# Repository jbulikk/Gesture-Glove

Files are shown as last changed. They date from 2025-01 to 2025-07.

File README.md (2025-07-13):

# Gesture Glove
The purpose of this project is to design and implement a prototype glove for gesture-based computer control, equipped with a set of sensors and a microcontroller. 

The project integrates flex sensors that measure finger bending and an inertial module containing an accelerometer and gyroscope, enabling gesture recognition based on spatial orientation. A key system component is the decision unit, which analyses sensor data and compares it with predefined patterns. Recognized
gestures are then transmitted to the computer via a USB HID interface.

The designed PCB, measuring 47.5 mm by 54.5 mm, was created to optimize the system's dimensions and facilitate durable mounting on the glove.
The results include successful recognition gestures and seamless
integration with the computer via USB HID. 

Future development plans involve further PCB miniaturization using a dedicated integrated circuit, the introduction of a wireless communication interface, and the design of a battery-powered system. Additionally, optimization of the decision algorithm is planned to improve gesture recognition accuracy.

# Overview

🎥 [Demo 1](https://youtube.com/shorts/HhJ9UxrMhsA?si=5mQ5Ls-5uZ076j6t)
🎥 [Demo 2](https://youtube.com/shorts/HhJ9UxrMhsA?si=OoEMOWHLwrecI-b9)


rekawica

pajak

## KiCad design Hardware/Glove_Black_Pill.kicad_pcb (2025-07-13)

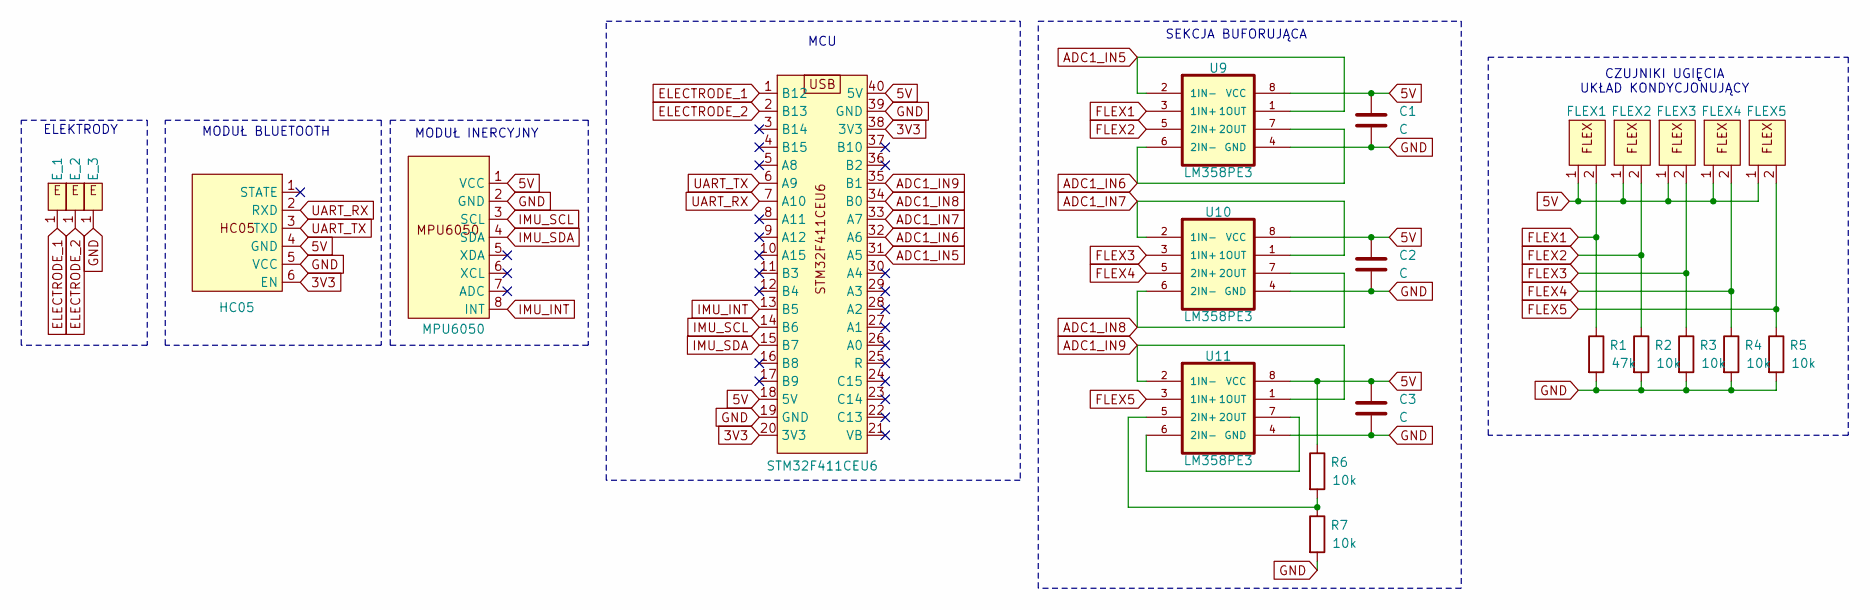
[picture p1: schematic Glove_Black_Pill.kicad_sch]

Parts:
C1, C2, C3: C; R_0805_2012Metric_Pad1.20x1.40mm_HandSolder
E_1, E_2, E_3: TestPoint_Loop_D2.50mm_Drill1.0mm
FLEX1, FLEX2, FLEX3, FLEX4, FLEX5: FLEX
HC05: HC-05
MPU6050: MPU6050
R1: 47k; R_0805_2012Metric_Pad1.20x1.40mm_HandSolder
R2, R3, R4, R5, R6, R7: 10k; R_0805_2012Metric_Pad1.20x1.40mm_HandSolder
STM32F411CEU6: STM32F411CEU6
U9, U10, U11: LM358PE3; DIP794W45P254L959H508Q8

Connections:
3V3: HC05.6 (EN), STM32F411CEU6.20 (3V3), STM32F411CEU6.38 (3V3)
5V: C1.1, C2.1, C3.1, FLEX1.1, FLEX2.1, FLEX3.1, FLEX4.1, FLEX5.1, HC05.4 (GND), MPU6050.1 (VCC), R6.1, STM32F411CEU6.18 (5V), STM32F411CEU6.40 (5V), U9.8 (VCC), U10.8 (VCC), U11.8 (VCC); also elsewhere on the board
ADC1_IN5: STM32F411CEU6.31 (A5), U9.1 (1OUT), U9.2 (1IN-)
ADC1_IN6: STM32F411CEU6.32 (A6), U9.6 (2IN-), U9.7 (2OUT)
ADC1_IN7: STM32F411CEU6.33 (A7), U10.1 (1OUT), U10.2 (1IN-)
ADC1_IN8: STM32F411CEU6.34 (B0), U10.6 (2IN-), U10.7 (2OUT)
ADC1_IN9: STM32F411CEU6.35 (B1), U11.1 (1OUT), U11.2 (1IN-)
ELECTRODE_1: E_1.1, STM32F411CEU6.1 (B12)
ELECTRODE_2: E_2.1, STM32F411CEU6.2 (B13)
FLEX1: FLEX1.2, R1.1, U9.3 (1IN+); also elsewhere on the board
FLEX2: FLEX2.2, R2.1, U9.5 (2IN+)
FLEX3: FLEX3.2, R3.1, U10.3 (1IN+)
FLEX4: FLEX4.2, R4.1, U10.5 (2IN+)
FLEX5: FLEX5.2, R5.1, U11.3 (1IN+)
GND: C1.2, C2.2, C3.2, E_3.1, HC05.5 (VCC), MPU6050.2 (GND), R1.2, R2.2, R3.2, R4.2, R5.2, R7.2, STM32F411CEU6.19 (GND), STM32F411CEU6.39 (GND), U9.4 (GND), U10.4 (GND), U11.4 (GND)
IMU_INT: MPU6050.8 (INT), STM32F411CEU6.13 (B5)
IMU_SCL: MPU6050.3 (SCL), STM32F411CEU6.14 (B6)
IMU_SDA: MPU6050.4 (SDA), STM32F411CEU6.15 (B7)
unnamed: R6.2, R7.1, U11.5 (2IN+)
unnamed: U11.6 (2IN-), U11.7 (2OUT)
UART_RX: HC05.2 (RXD), STM32F411CEU6.7 (A10)
UART_TX: HC05.3 (TXD), STM32F411CEU6.6 (A9)

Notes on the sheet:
MODUŁ BLUETOOTH
MODUŁ INERCYJNY
SEKCJA BUFORUJĄCA
ELEKTRODY
MCU
CZUJNIKI UGIĘCIA UKŁAD KONDYCJONUJĄCY

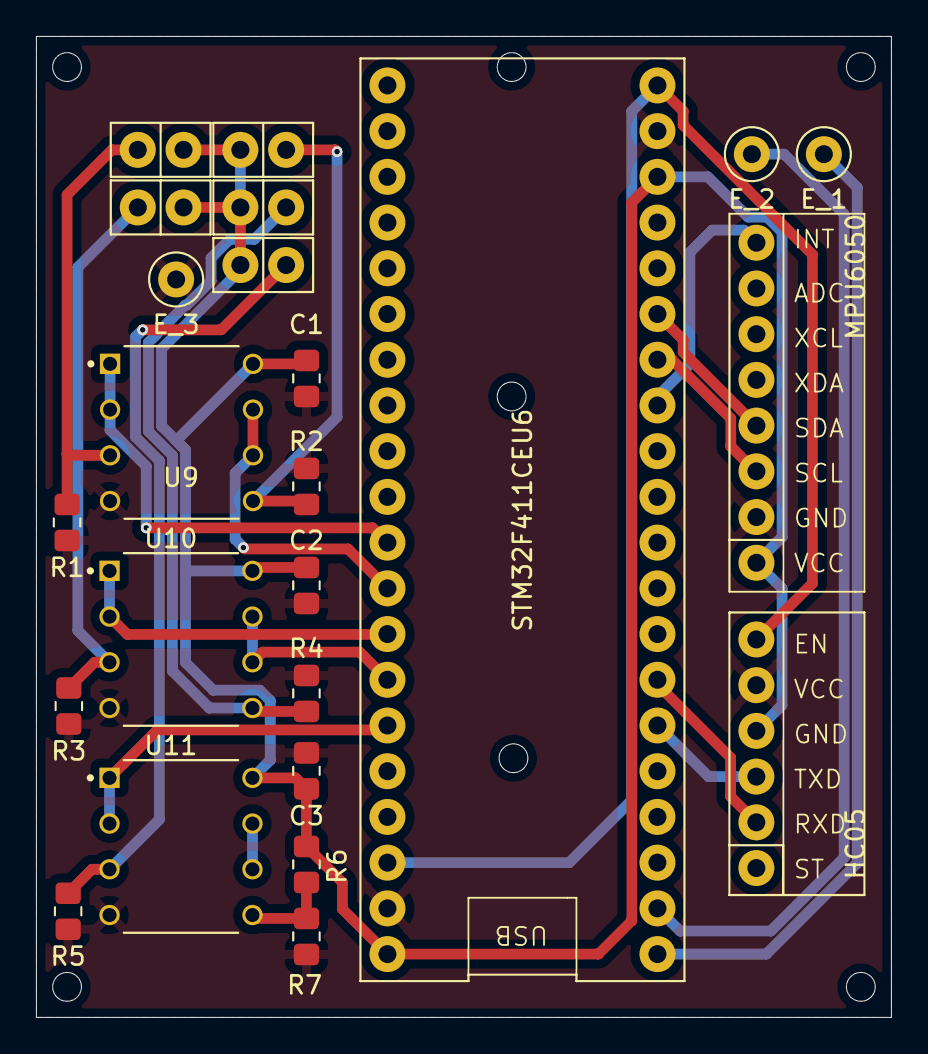
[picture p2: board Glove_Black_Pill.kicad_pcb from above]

Board: 4 copper layers, 47.5 x 54.5 mm, 24 parts (0 on the bottom side), 22 nets.

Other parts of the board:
.: FLEX

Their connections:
5V: ..1; also elsewhere on the board
FLEX1: ..2; also elsewhere on the board

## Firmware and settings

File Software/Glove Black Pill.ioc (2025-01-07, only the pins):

Mcu.UserName=STM32F411CEUx
PA10.Signal=USART1_RX
PA11.Signal=USB_OTG_FS_DM
PA12.Signal=USB_OTG_FS_DP
PA13.Signal=SYS_JTMS-SWDIO
PA14.Signal=SYS_JTCK-SWCLK
PA5.Signal=ADCx_IN5
PA6.Signal=ADCx_IN6
PA7.Signal=ADCx_IN7
PA9.Signal=USART1_TX
PB0.Signal=ADCx_IN8
PB1.Signal=ADCx_IN9
PB12.Signal=GPXTI12
PB13.Signal=GPXTI13
PB14.Signal=GPXTI14
PB5.Signal=GPXTI5
PB6.Signal=I2C1_SCL
PB7.Signal=I2C1_SDA

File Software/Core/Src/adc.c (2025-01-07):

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
/* Includes ------------------------------------------------------------------*/
#include "adc.h"

ADC_HandleTypeDef hadc1;
DMA_HandleTypeDef hdma_adc1;

/* ADC1 init function */
void MX_ADC1_Init(void)
{

  ADC_ChannelConfTypeDef sConfig = {0};

  /** Configure the global features of the ADC (Clock, Resolution, Data Alignment and number of conversion)
  */
  hadc1.Instance = ADC1;
  hadc1.Init.ClockPrescaler = ADC_CLOCK_SYNC_PCLK_DIV2;
  hadc1.Init.Resolution = ADC_RESOLUTION_12B;
  hadc1.Init.ScanConvMode = ENABLE;
  hadc1.Init.ContinuousConvMode = ENABLE;
  hadc1.Init.DiscontinuousConvMode = DISABLE;
  hadc1.Init.ExternalTrigConvEdge = ADC_EXTERNALTRIGCONVEDGE_NONE;
  hadc1.Init.ExternalTrigConv = ADC_SOFTWARE_START;
  hadc1.Init.DataAlign = ADC_DATAALIGN_RIGHT;
  hadc1.Init.NbrOfConversion = 7;
  hadc1.Init.DMAContinuousRequests = ENABLE;
  hadc1.Init.EOCSelection = ADC_EOC_SEQ_CONV;
  if (HAL_ADC_Init(&hadc1) != HAL_OK)
  {
    Error_Handler();
  }

  /** Configure for the selected ADC regular channel its corresponding rank in the sequencer and its sample time.
  */
  sConfig.Channel = ADC_CHANNEL_9;
  sConfig.Rank = 1;
  sConfig.SamplingTime = ADC_SAMPLETIME_144CYCLES;
  if (HAL_ADC_ConfigChannel(&hadc1, &sConfig) != HAL_OK)
  {
    Error_Handler();
  }

  /** Configure for the selected ADC regular channel its corresponding rank in the sequencer and its sample time.
  */
  sConfig.Channel = ADC_CHANNEL_8;
  sConfig.Rank = 2;
  if (HAL_ADC_ConfigChannel(&hadc1, &sConfig) != HAL_OK)
  {
    Error_Handler();
  }

  /** Configure for the selected ADC regular channel its corresponding rank in the sequencer and its sample time.
  */
  sConfig.Channel = ADC_CHANNEL_7;
  sConfig.Rank = 3;
  if (HAL_ADC_ConfigChannel(&hadc1, &sConfig) != HAL_OK)
  {
    Error_Handler();
  }

  /** Configure for the selected ADC regular channel its corresponding rank in the sequencer and its sample time.
  */
  sConfig.Channel = ADC_CHANNEL_6;
  sConfig.Rank = 4;
  if (HAL_ADC_ConfigChannel(&hadc1, &sConfig) != HAL_OK)
  {
    Error_Handler();
  }

  /** Configure for the selected ADC regular channel its corresponding rank in the sequencer and its sample time.
  */
  sConfig.Channel = ADC_CHANNEL_5;
  sConfig.Rank = 5;
  if (HAL_ADC_ConfigChannel(&hadc1, &sConfig) != HAL_OK)
  {
    Error_Handler();
  }

  /** Configure for the selected ADC regular channel its corresponding rank in the sequencer and its sample time.
  */
  sConfig.Rank = 6;
  if (HAL_ADC_ConfigChannel(&hadc1, &sConfig) != HAL_OK)
  {
    Error_Handler();
  }

  /** Configure for the selected ADC regular channel its corresponding rank in the sequencer and its sample time.
  */
  sConfig.Rank = 7;
  if (HAL_ADC_ConfigChannel(&hadc1, &sConfig) != HAL_OK)
  {
    Error_Handler();
  }
}

void HAL_ADC_MspInit(ADC_HandleTypeDef* adcHandle)
{

  GPIO_InitTypeDef GPIO_InitStruct = {0};
  if(adcHandle->Instance==ADC1)
  {
    /* ADC1 clock enable */
    __HAL_RCC_ADC1_CLK_ENABLE();

    __HAL_RCC_GPIOA_CLK_ENABLE();
    __HAL_RCC_GPIOB_CLK_ENABLE();
    /**ADC1 GPIO Configuration
    PA5     ------> ADC1_IN5
    PA6     ------> ADC1_IN6
    PA7     ------> ADC1_IN7
    PB0     ------> ADC1_IN8
    PB1     ------> ADC1_IN9
    */
    GPIO_InitStruct.Pin = GPIO_PIN_5|GPIO_PIN_6|GPIO_PIN_7;
    GPIO_InitStruct.Mode = GPIO_MODE_ANALOG;
    GPIO_InitStruct.Pull = GPIO_NOPULL;
    HAL_GPIO_Init(GPIOA, &GPIO_InitStruct);

    GPIO_InitStruct.Pin = GPIO_PIN_0|GPIO_PIN_1;
    GPIO_InitStruct.Mode = GPIO_MODE_ANALOG;
    GPIO_InitStruct.Pull = GPIO_NOPULL;
    HAL_GPIO_Init(GPIOB, &GPIO_InitStruct);

    /* ADC1 DMA Init */
    /* ADC1 Init */
    hdma_adc1.Instance = DMA2_Stream0;
    hdma_adc1.Init.Channel = DMA_CHANNEL_0;
    hdma_adc1.Init.Direction = DMA_PERIPH_TO_MEMORY;
    hdma_adc1.Init.PeriphInc = DMA_PINC_DISABLE;
    hdma_adc1.Init.MemInc = DMA_MINC_ENABLE;
    hdma_adc1.Init.PeriphDataAlignment = DMA_PDATAALIGN_HALFWORD;
    hdma_adc1.Init.MemDataAlignment = DMA_MDATAALIGN_HALFWORD;
    hdma_adc1.Init.Mode = DMA_CIRCULAR;
    hdma_adc1.Init.Priority = DMA_PRIORITY_LOW;
    hdma_adc1.Init.FIFOMode = DMA_FIFOMODE_DISABLE;
    if (HAL_DMA_Init(&hdma_adc1) != HAL_OK)
    {
      Error_Handler();
    }

    __HAL_LINKDMA(adcHandle,DMA_Handle,hdma_adc1);

    /* ADC1 interrupt Init */
    HAL_NVIC_SetPriority(ADC_IRQn, 0, 0);
    HAL_NVIC_EnableIRQ(ADC_IRQn);
  }
}

void HAL_ADC_MspDeInit(ADC_HandleTypeDef* adcHandle)
{

  if(adcHandle->Instance==ADC1)
  {
    /* Peripheral clock disable */
    __HAL_RCC_ADC1_CLK_DISABLE();

    /**ADC1 GPIO Configuration
    PA5     ------> ADC1_IN5
    PA6     ------> ADC1_IN6
    PA7     ------> ADC1_IN7
    PB0     ------> ADC1_IN8
    PB1     ------> ADC1_IN9
    */
    HAL_GPIO_DeInit(GPIOA, GPIO_PIN_5|GPIO_PIN_6|GPIO_PIN_7);

    HAL_GPIO_DeInit(GPIOB, GPIO_PIN_0|GPIO_PIN_1);

    /* ADC1 DMA DeInit */
    HAL_DMA_DeInit(adcHandle->DMA_Handle);

    /* ADC1 interrupt Deinit */
    HAL_NVIC_DisableIRQ(ADC_IRQn);
  }
}



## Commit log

2024-12-02 Adding interrupts on both edges on pins 12 and 13
2024-12-20 changed fingers order due to pcb
2024-12-22 Change in the operation of the decision-making unit, checking the initial values of adc, changed low pass filter and alpha value
2025-01-07 decision unit checks every finger, flag and assign fingers values after all conversions
2025-01-07 adding pitch calculations
2025-01-07 Handling of electrodes, limitation of gesture recognition
2025-07-13 project restructure, adding hardware
    [Glove_Black_Pill.kicad_pcb, Glove_Black_Pill.kicad_sch]

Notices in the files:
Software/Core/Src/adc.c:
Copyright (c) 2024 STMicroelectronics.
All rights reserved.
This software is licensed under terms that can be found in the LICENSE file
